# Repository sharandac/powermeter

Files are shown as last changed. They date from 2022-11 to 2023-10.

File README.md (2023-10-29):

<p align="center">

&nbsp;

&nbsp;

</p>
<hr/>

# powermeter

A not so simple but very flexible smart meter based on ESP32. It supports MQTT, live monitoring via web interface, IO ports ( can be switched depending on measured values ), a simple OLED driver for simple value reports, editable opcode sequences per channel and group management. And the best is: everything can also be set via the web interface and has immediate effect and invites to play to improve the understanding of AC voltage/current or DC voltage/current.<br>
<h3 style="color:#00ff00">Note: From version 2022110101 a complete reconfiguration is required.</h3>
<h3 style="color:#ff0000">Danger: Working with 110V or 230V is dangerous!</h3>

# install

Clone this repository and open it with platformIO. Remember, the SPIFF must also be flashed. On a terminal in vscode you can do it with
```bash
pio run -t uploadfs
pio run -t upload
```

After that, take a look at your monitorport ...

```text
Read config from SPIFFS
scan for SSID "" ... not found
starting Wifi-AP with SSID "powermeter_aadee0"
AP IP address: 192.168.4.1
Start Main Task on Core: 1
Start NTP Task on Core: 1
Start Measurement Task on Core: 0
Start MQTT-Client on Core: 1
Start Webserver on Core: 1
NTP-client: renew time
Start OTA Task on Core: 1
Failed to obtain time
NTP-client: Thursday, January 01 1970 01:00:07
```
When the output look like this, congratulation!

After the first start an access point will be opened with an unique name like
```bash
powermeter_XXXXX
```
and an not so unique password
```bash
powermeter
```
After that you can configure the powermeter under the following IP-address with your favorite webbrowser
```bash
http://192.168.4.1 or powermeter_xxxxxx.local
```
# how it works

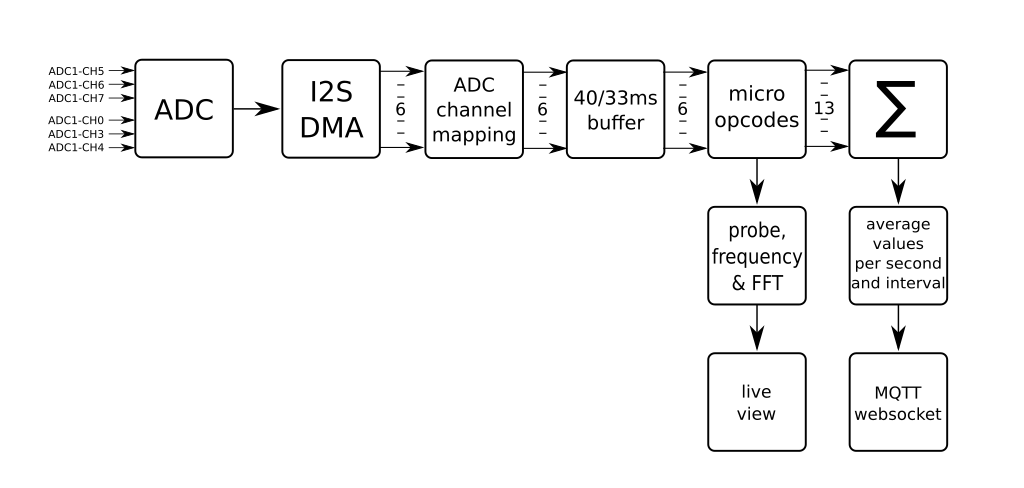
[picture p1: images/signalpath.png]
signalpath


At any time, all 6 adc channel are read in simultaneously regardless of the settings. Afterwards, these 6 ADC channels are distributed to 13 virtual channels with the help of editable microopcodes, each sample has a maximum of 10 opcodes available for real-time calculations (mixing, sum calculation, reactive power and so on). These 13 virtual channels can then be combined into a maximum of 6 output groups. For more information about how AC current or three-phase current and power calculations works, [read here](https://en.wikipedia.org/wiki/Alternating_current) and [here](https://en.wikipedia.org/wiki/Three-phase_electric_power)

# sensor hardware

## Sensors
SCT013-000 current sensor (~100A)<br>
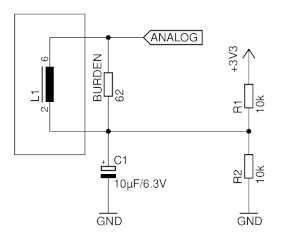
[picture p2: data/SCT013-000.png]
SCT013-000 current sensor (~100A)


ZMPT101B voltage sensor (~250V)<br>
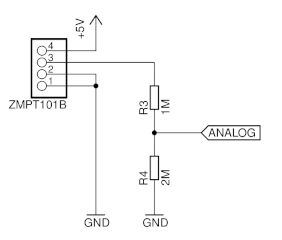
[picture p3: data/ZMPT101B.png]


ACS712 current sensor 5A, 20A and 30A<br>
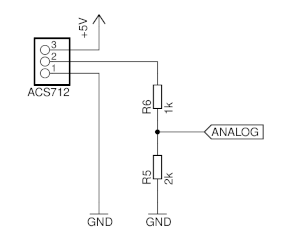
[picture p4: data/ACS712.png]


simple voltage divider<br>
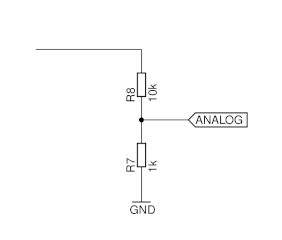
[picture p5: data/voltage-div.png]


For ratio calculation see inline documentation via webinterface.

## Display hardware
Uncomment in "**display.cpp**" the line of the display you want to use<br>
```c
//#include <Adafruit_SSD1306.h>
//#include  <Adafruit_SH110X.h>
```

# Interface

## live view
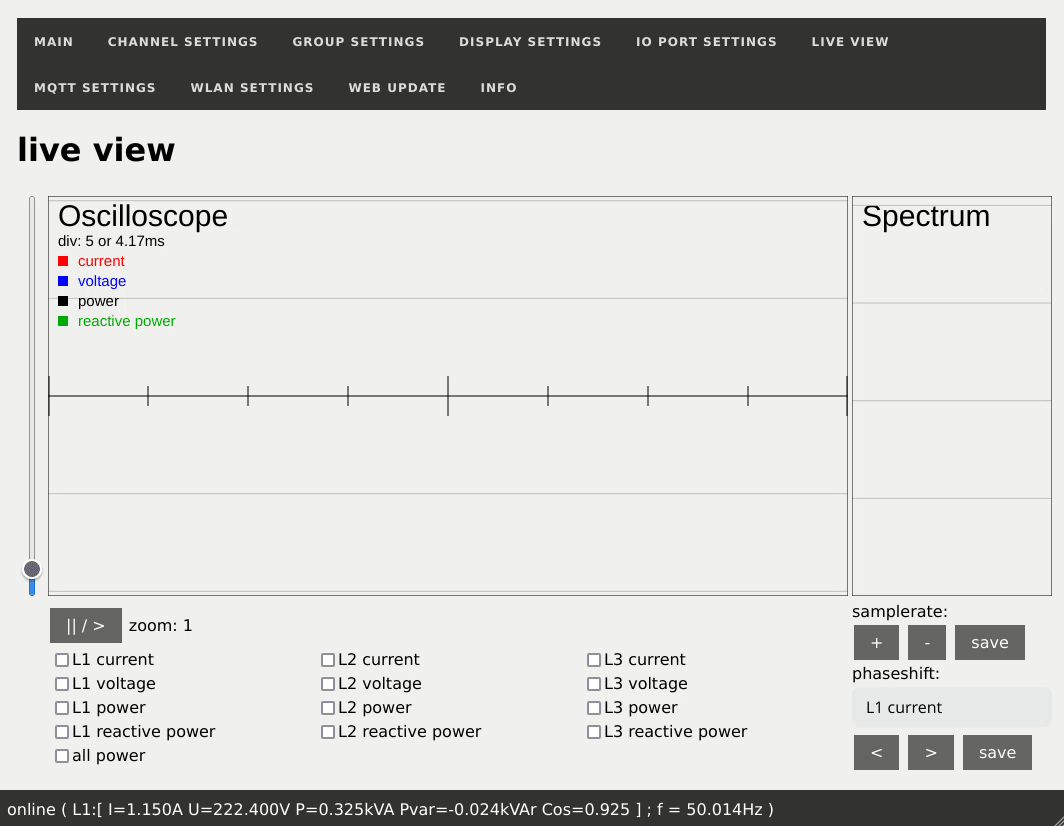
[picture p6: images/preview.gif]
live view

## round trip
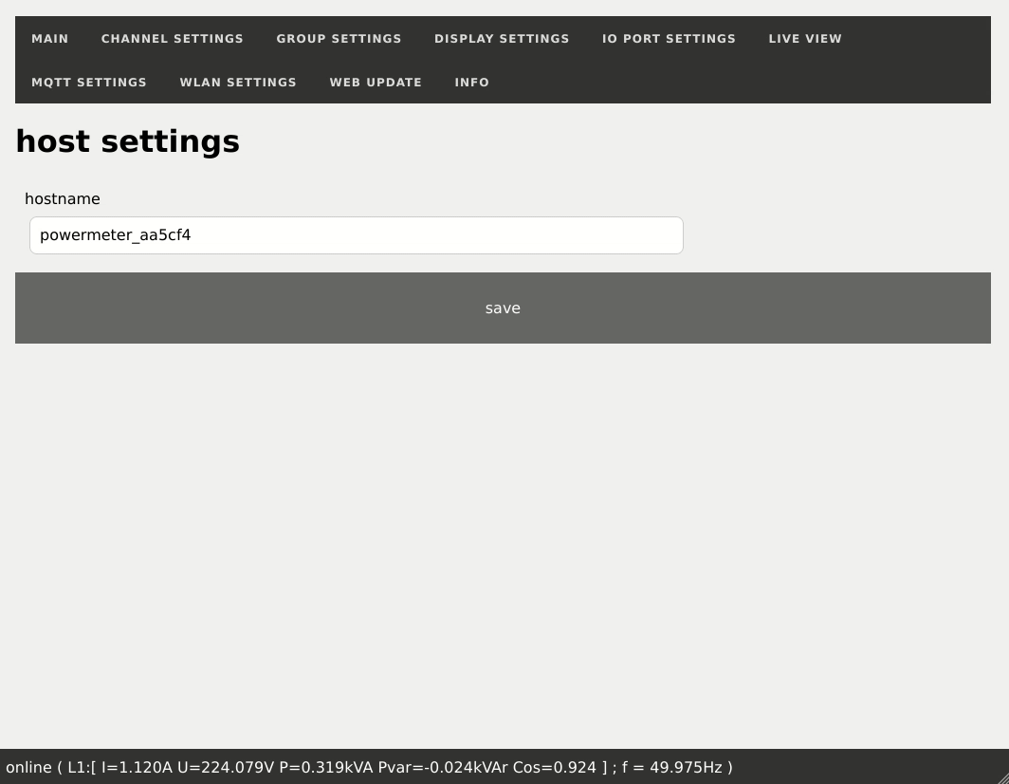
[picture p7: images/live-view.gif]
round trip


# contributors

Every Contribution to this repository is highly welcome! Don't fear to create pull requests which enhance or fix the project, you are going to help everybody.
<p>
If you want to donate to the author then you can buy me a coffee.
<br/><br/>

</p>

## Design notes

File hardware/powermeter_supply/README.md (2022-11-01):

# powermeter with supply

Here is the simplest standalone powermeter with supply you can build with current and voltage measurement.

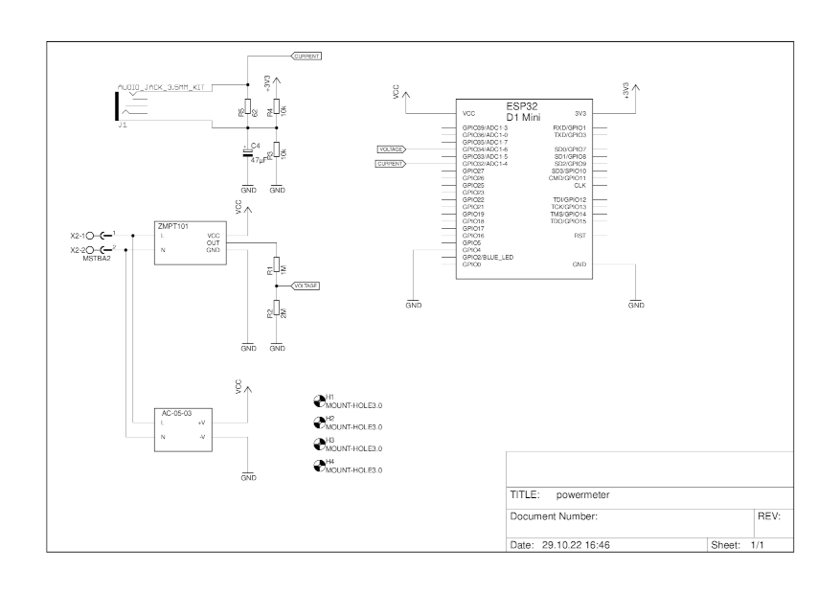
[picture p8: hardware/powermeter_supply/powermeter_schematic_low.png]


## eagle files

[schematic](powermeter.sch)<br>
[board](powermeter.brd)

## bill of material

1 x 150x100x1mm 35µm FR4 [amazon](https://amzn.eu/d/hufknsN)<br>
esp32 D1 mini [amazon](https://amzn.eu/d/gZaocqF)<br>
ZMPT101 [amazon](https://amzn.eu/d/3shv3Ax)<br>
SCT-013-000 [amazon](https://amzn.eu/d/5wpwDs4)<br>
AC-05-03 ( 110-250V/AC -> 5V/DC ) [amazon](https://amzn.eu/d/ckoURve)<br>
3.5mm jack [amazon](https://amzn.eu/d/a7YUG0G)<br>
MSTBA2 connector [amazon](https://amzn.eu/d/0bCERTn)<br>
2 x 10k resistor<br>
1 x 62R resistor<br>
1 x 1M resistor<br>
1 x 2M resistor<br>
1 x 47µF cap<br>

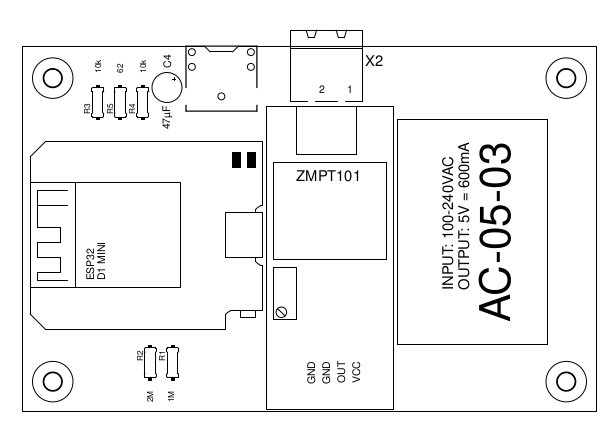
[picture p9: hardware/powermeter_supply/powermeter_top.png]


## gcode

The G-code files are intended for Chilipeppr with a CNC3018 and contain everything. Engraving, drilling and cutting. There are two files. A normal one, where you should have your own gcode for tool change and length measurement and one with the appropriate gcode that also contains the length measurement. The reference point is X=0 and Y=0.

A backlash-free Z-axis is very important for accurate engraving of the tracks and cutting out!

The following tools are required:

0.1mm milling bit<br>
0.6mm drill bit<br>
0.9mm drill bit<br>
1.2mm drill bit<br>
1.3mm drill bit<br>
1.4mm drill bit<br>
2.0mm end mill<br>

Drag and drop the preferred gcode file into Chilipeppr. Autoleveling is a must. And then just press play. For the tool change, the program is paused at the appropriate position (M6).

If everything has gone well, you are rewarded with a finished board without any post-processing and is ready to soldering.

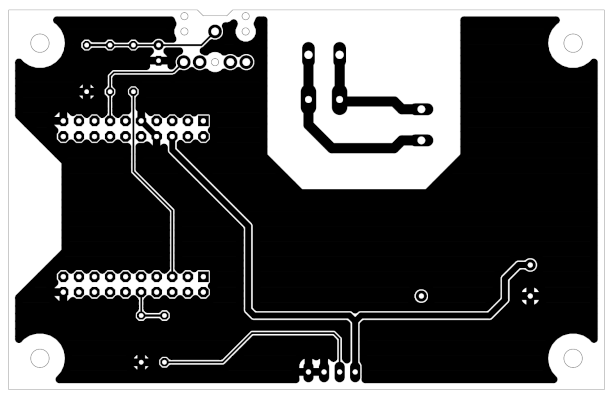
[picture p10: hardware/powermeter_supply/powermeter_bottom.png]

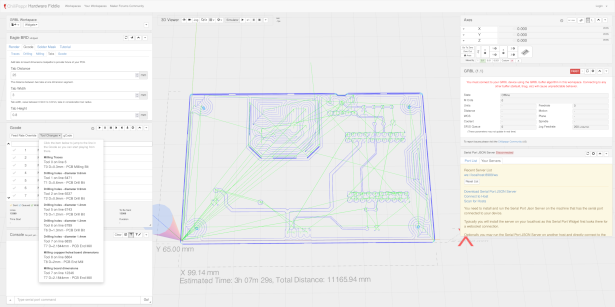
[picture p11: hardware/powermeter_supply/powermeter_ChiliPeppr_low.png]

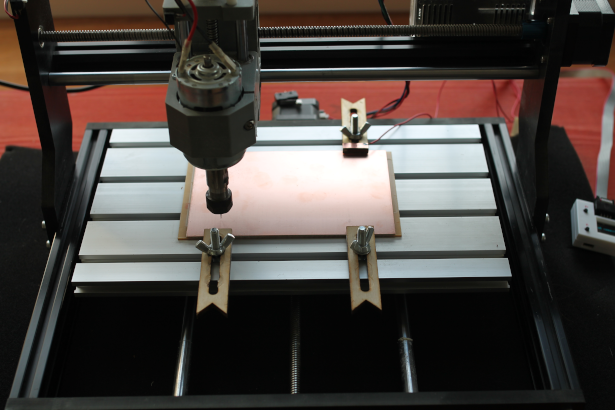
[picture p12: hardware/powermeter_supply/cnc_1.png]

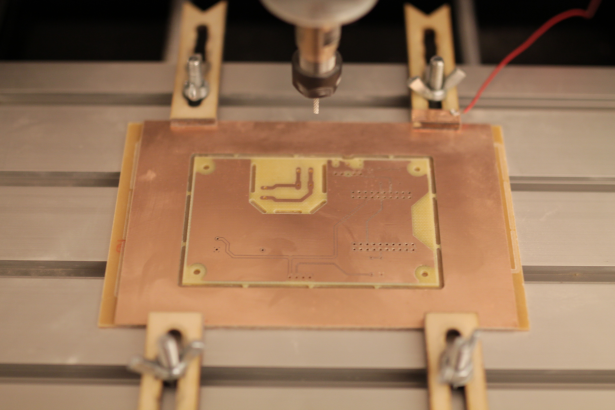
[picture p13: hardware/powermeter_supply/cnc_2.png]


## config

After soldering and software installtion (wifi,mqtt and so on) you can copy the content from config/measure.json to your powermeter. From here you can tweake the ratio settings for precise measuring via web interface under "channel settings".

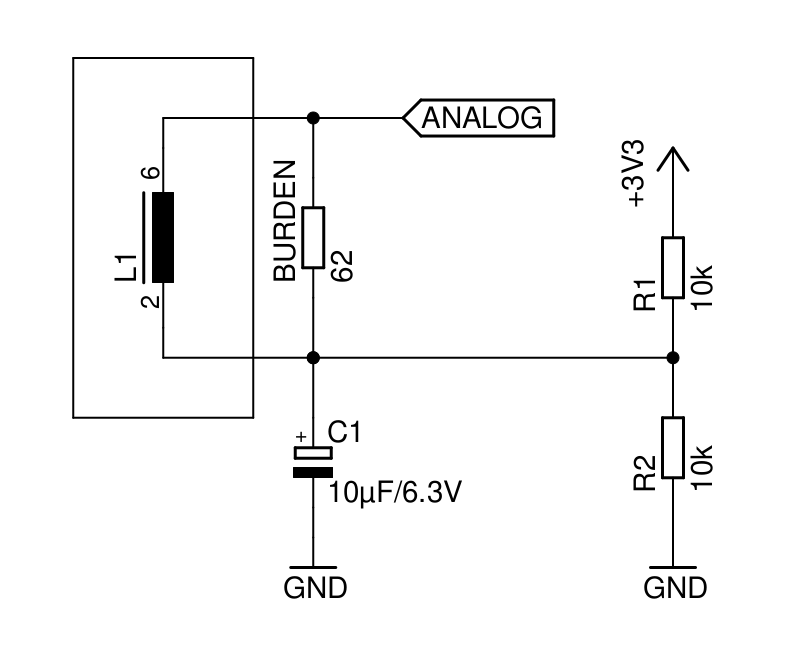
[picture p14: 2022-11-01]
images/schematic.png

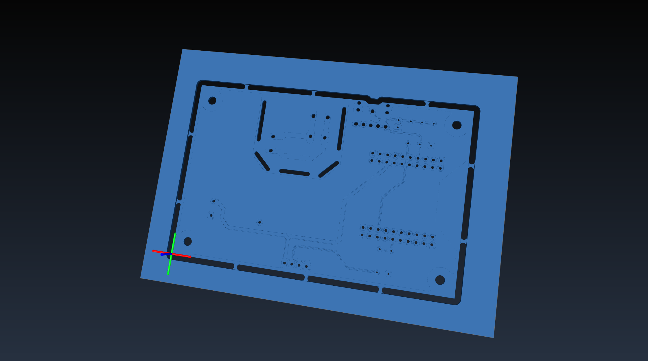
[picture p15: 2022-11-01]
hardware/powermeter_supply/gocde/powermeter.png

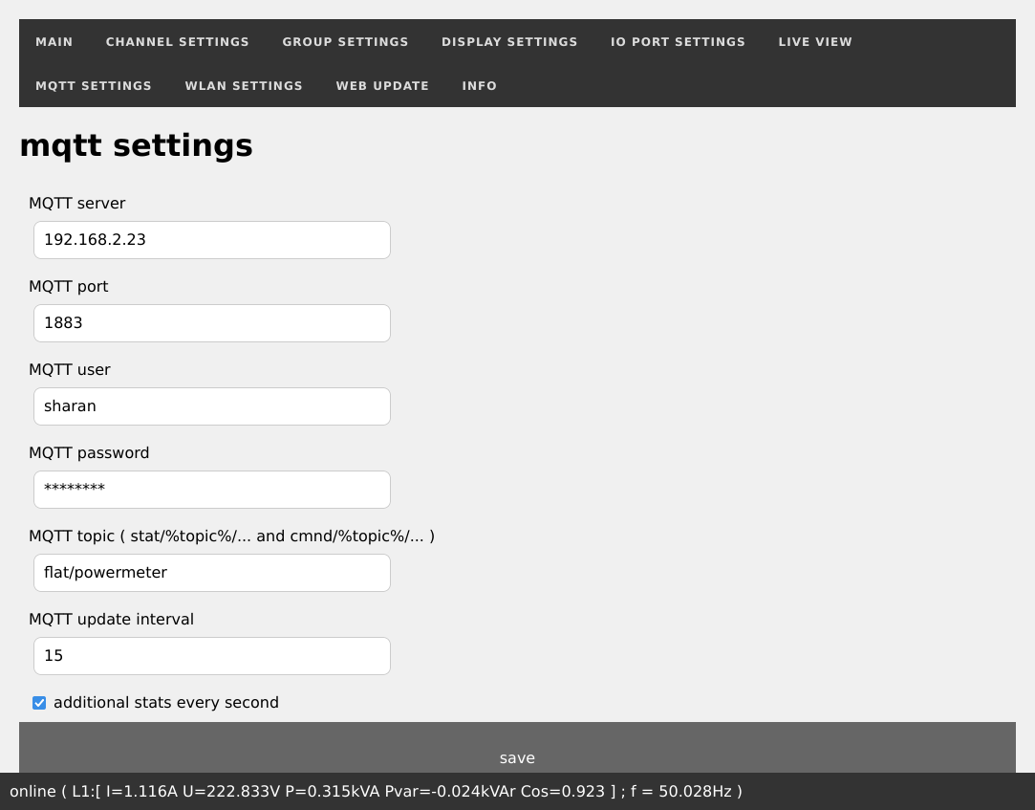
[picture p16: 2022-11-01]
images/mqtt-setting.png

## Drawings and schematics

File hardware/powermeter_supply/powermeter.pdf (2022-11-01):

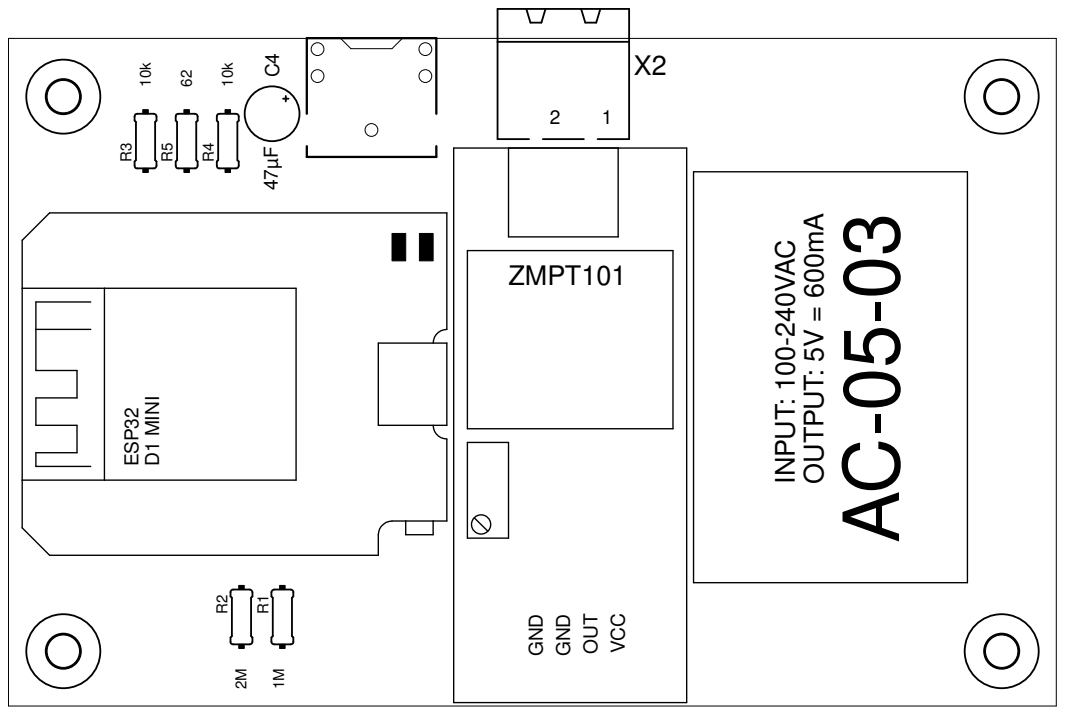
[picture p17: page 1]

ESP32 D1 MINI VCC OUT GND GND ZMPT101 2 1 AC-05-03 INPUT: 100-240VAC OUTPUT: 5V = 600mA R1 R2 R3 R4 R5 C4X2 1M2M 10k 10k 62 47µF

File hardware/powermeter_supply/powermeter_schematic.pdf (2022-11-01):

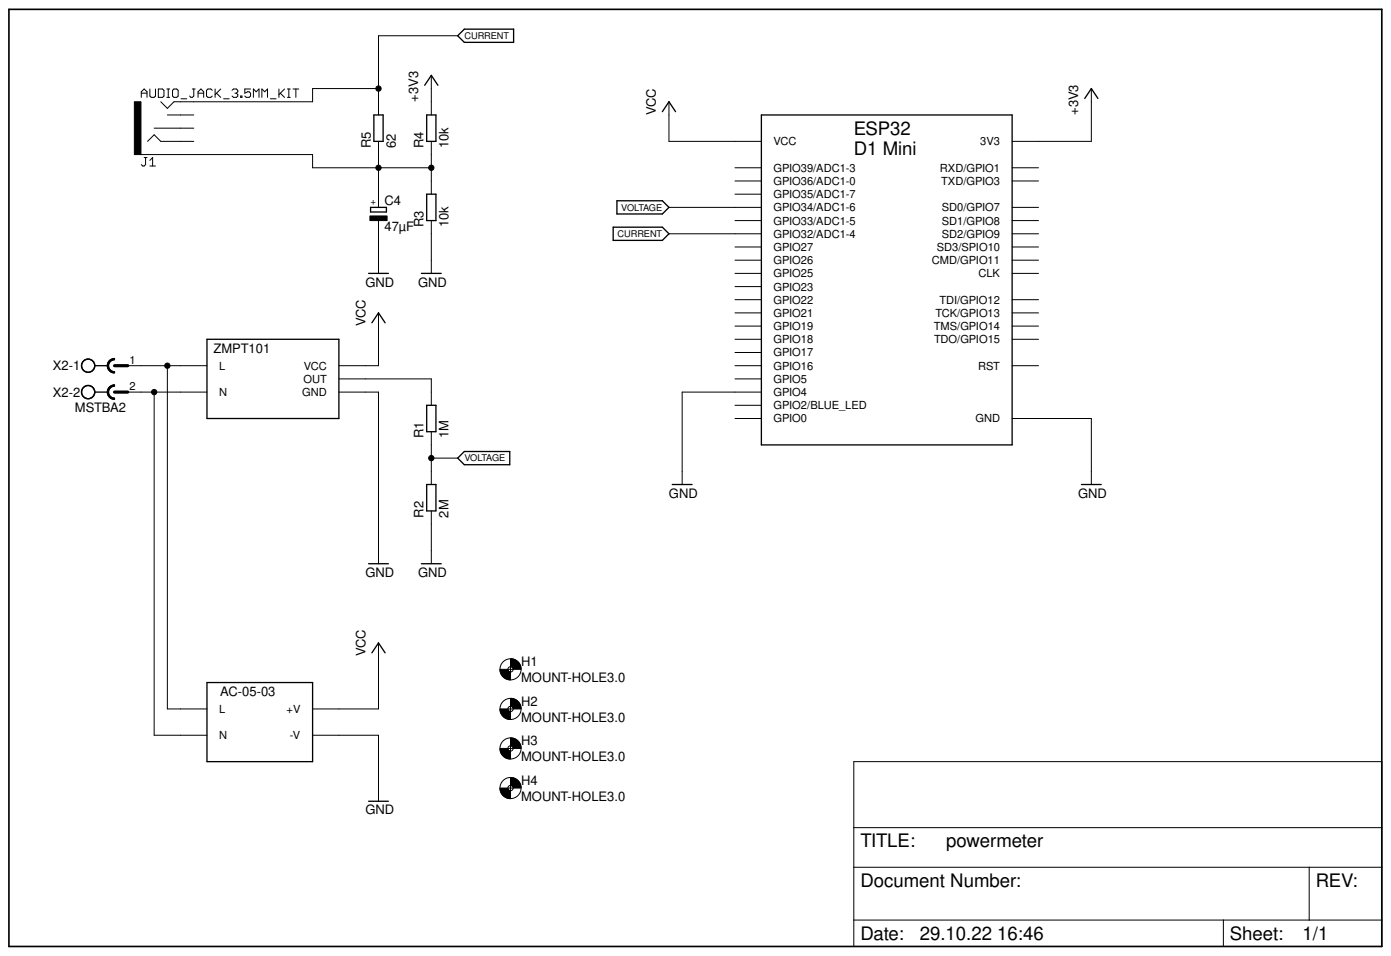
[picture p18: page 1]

Document Number: | REV:

Date: 29.10.22 16:46 | Sheet: 1/1

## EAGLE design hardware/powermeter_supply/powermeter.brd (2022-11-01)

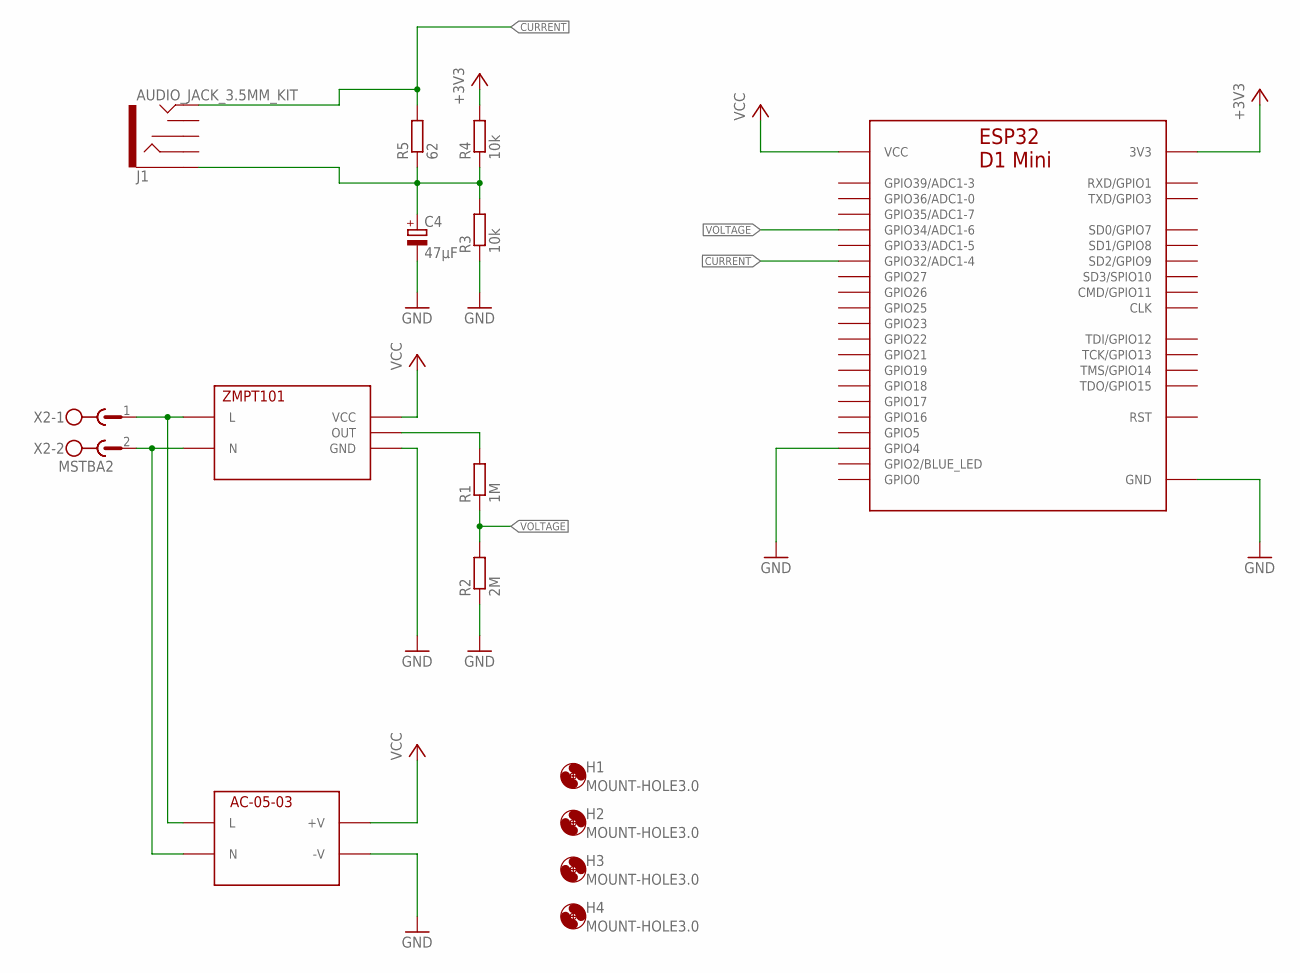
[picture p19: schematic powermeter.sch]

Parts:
C4: 47µF; E2,5-5
H1, H2, H3, H4: MOUNT-HOLE3.0; 3,0
J1: AUDIO_JACK_3.5MM_KIT; AUDIO-JACK-KIT
R1: 1M; 0204/7
R2: 2M; 0204/7
R3, R4: 10k; 0204/7
R5: 62; 0204/7
U1: ESP32D1MINI
U$1: ZMPT101
U$2: AC-05-03
X2: MSTBA2

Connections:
+3V3: R4.2, U1.3V3
CURRENT: J1.TIP, R5.2, U1.IO32 (GPIO32/ADC1-4)
GND: C4.-, R2.1, R3.1, U1.GND1 (GND), U1.GND2 (GND), U1.GND3 (GND), U1.IO4 (GPIO4), U$1.P$3 (GND), U$1.P$4 (GND), U$2.-V
unnamed: R1.2, U$1.OUT
unnamed: U$1.L, U$2.L, X2.1
unnamed: C4.+, J1.SLEEVE, R3.2, R4.1, R5.1
unnamed: U$1.N, U$2.N, X2.2
VCC: U1.VCC, U$1.VCC, U$2.+V
VOLTAGE: R1.1, R2.2, U1.IO34 (GPIO34/ADC1-6)

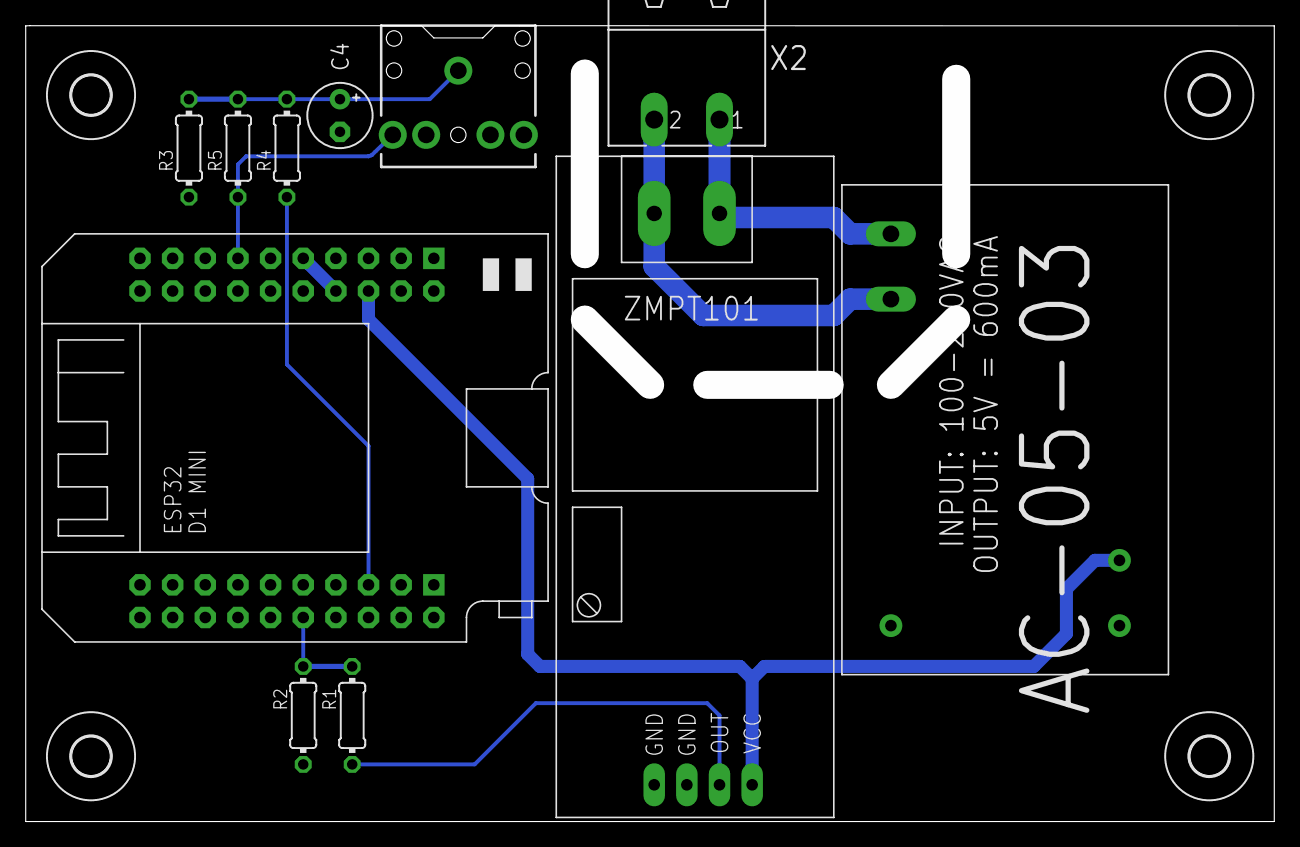
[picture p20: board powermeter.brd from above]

Board: 2 copper layers, 97.1 x 61.9 mm, 15 parts (0 on the bottom side), 9 nets.

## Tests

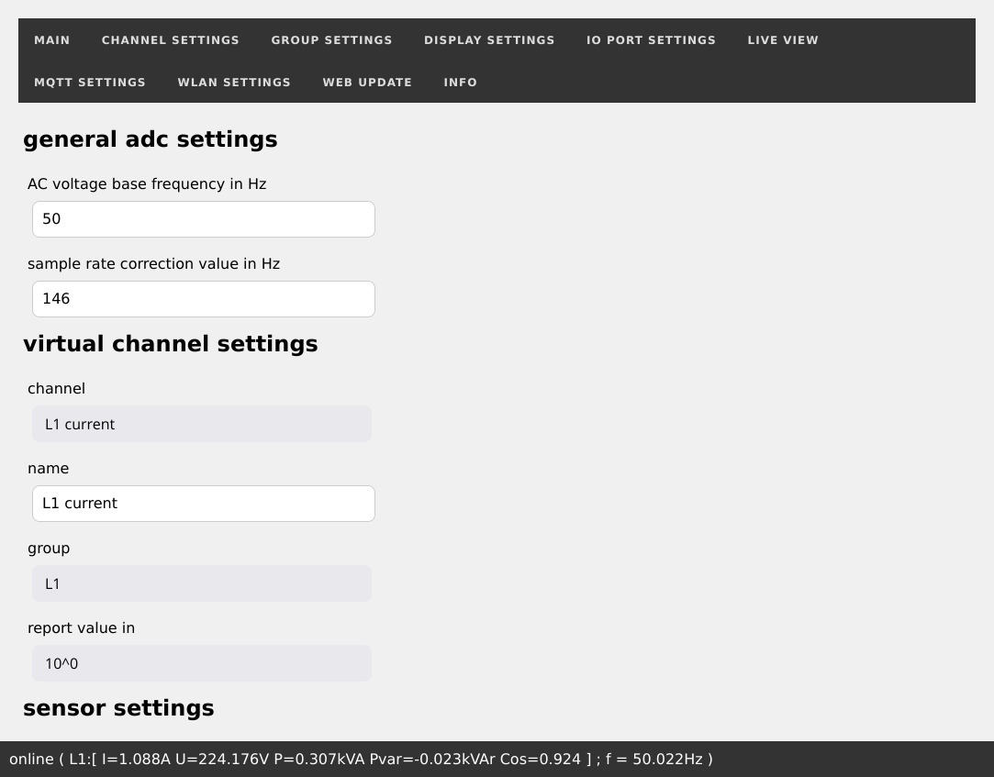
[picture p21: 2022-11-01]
images/measurement-setting.png

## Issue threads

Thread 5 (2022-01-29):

Unable connect to wifi network

STableThink, 2022-01-29:
When trying to connect to my own personal wifi ap (and other test access points), the debug console only shows this error at startup:
```
scan for SSID "stsopenwrt" ... found
connect to stsopenwrt (****)
WiFi lost, restart ... failed
starting Wifi-AP with SSID "powermeter1"
```
So the esp is unable to log into my home network.
Best regards
Jonas

sharandac, 2022-03-22:
Thanks for your feedback. I have also seen this error from time to time. The ESP32 will probably connect correctly to your network later when your settings are right. With Firefox, you can then connect to "http://powermeter1.local" without knowing the IP.

"powermeter1" is your Wifi AP SSID in this case.

Otherwise, let me know ...

Closed 2022-04-28.

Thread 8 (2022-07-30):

Question: Precision for 3phase setup?

gytisgreitai, 2022-07-30:
Hi, thanks for the nice write up and detailed diagram! I have a bit offtopic question, how precise do you find the readings of these clamps without voltage measuring? I’m contemplating about using this diy vs buying ready made product like shelly. Do you calibrate them somehow?

sharandac, 2022-08-01:
Thank you for your feedback. The square-root measurement method is quite accurate, even if the ADC is not. Just like the SCT-013-0x0 converters. But that's not a problem if you have a consumer from which you know the exact power consumption. With this, you can calibrate everything precisely.
I have an exact 2kW consumer that has been precisely measured for me.
I get +/-0.5 % accuracy with 2kW. Of course, as with all measuring methods, it becomes less accurate in the lower range.
The voltage can also be measured using the same method (small 9 V transformer or [link](https://www.amazon.de/gp/product/B08ZDQ77ZC/ref=ppx_yo_dt_b_asin_title_o04_s00?ie=UTF8&psc=1)) and then calculated. Or you can simply enter 230 or 110 volts.
I also recommend using the experimental branch, which works better but is not yet completely finished because I lack some time.

Closed 2022-08-11.

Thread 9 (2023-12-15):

Saving settings

Vovick1971, 2023-12-15:
Hello.
Thank you for the work you've done. I have been looking for a similar project for a very long time. It is completely suitable for my tasks.
In my device, I use ESP 32 and ZMPT101B modules to measure mains voltage.
I have one unclear point.
 On the "channel settings" page, I select the voltage measurement channel (for example, L1 voltage), the sensor type (ZMPT101B), set the
 coefficients, save the settings (SAVE button at the bottom of the page), everything works correctly, but if you restart the EPS32 web
 interface page, or restart the module itself, then all settings return to default values (SCT013-000). In this case, incorrect values are
 output. You have to set the parameters again.
 Setting the checkbox to allow real time editing, but don't forget to save your settings also has no effect.
 I can't figure out how to make the set values persist.

Thank you.

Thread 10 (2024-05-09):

error: 'arduinoFFT' was not declared in this scope`

samezrp, 2024-05-09:
If any of you would have compile error:
`src/measure.cpp:480:9: error: 'arduinoFFT' was not declared in this scope`
please be aware lib kosme/arduinoFFT@=1.5.6 is not backword compatible.

Easiest solution is to update _platformio.ini_ file and change:
`kosme/arduinoFFT@>=1.5.6`
to
`kosme/arduinoFFT@=1.5.6`

**>=** replace with **=**

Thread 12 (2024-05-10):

L2 filter problem

samezrp, 2024-05-10:
I would like to rise another problem.
I'm preparing my implementation of your PowerMeter and I can see there is a problem with channel connected to: ADC1-CH7 (GPIO35).
I have HW with all 3 current lines connected to SCT013-030 installed on the same wire + 3 ZMPT101B fed with the same voltage. So all 3 voltage and 3 current reading should be the same.
And when you look at live view all is the same, but when you take a closer look at L2 and current, it is seen that this value is different and is not stable as others.
Take a look at this video:
[https://youtu.be/L46QpZTydEg](url)
on oscilloscope readings for L1 and L2 are the same. But when you look at spectrum and filtered value you can see difference. On spectrum you can see some pumping, L2 value jumps.
All channels are set the same, my measure.json file below.
@sharandac would you mind helping me with that?
[measure.json](https://github.com/sharandac/powermeter/files/15274634/measure.json)
I checked different ESP32 boards, I played with sensors, channels and look like problem is attached to: ADC1-CH7 (GPIO35) directly.

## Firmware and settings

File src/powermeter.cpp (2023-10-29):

/**
 * @file powermeter.cpp
 * @author Dirk Broßwick (dirk.brosswick@googlemail.com)
 * @brief 
 * @version 1.0
 * @date 2022-10-03
 * 
 * @copyright Copyright (c) 2022
 * 
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
 *  You should have received a copy of the GNU General Public License
 *  along with this program; if not, write to the Free Software
 *  Foundation, Inc., 59 Temple Place - Suite 330, Boston, MA 02111-1307, USA.
 */ 
#include <Arduino.h>
#include <FS.h>
#include <SPIFFS.h>

#include "config.h"
#include "display.h"
#include "ioport.h"
#include "measure.h"
#include "mqttclient.h"
#include "ntp.h"
#include "webserver.h"
#include "wificlient.h"
/**
 * @brief arduino setup function
 */
void setup( void ) {
    setCpuFrequencyMhz( 240 );
    Serial.begin(115200);
    /*
     * hardware stuff and file system
     */
    log_i("Start Main Task on Core: %d", xPortGetCoreID() );
    if ( !SPIFFS.begin() ) {
        log_i("format SPIFFS ..." );
        SPIFFS.format();
    }
    ioport_init();
    display_init();
    wificlient_init();
    /*
     * Setup Tasks
     */
    measure_StartTask();
    mqtt_client_StartTask();
    asyncwebserver_StartTask();
    ntp_StartTask();
}

/**
 * @brief arduino main loop
 */
void loop() {
    display_loop();
    ioport_loop();
}

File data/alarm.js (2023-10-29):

var pause_osc = true;
var connect = false;
var timeout = 3;
var savecounter = 0;
var connection;

getconnect();
setInterval(function () {getStatus();}, 1000);

function getconnect() {
    connection = new WebSocket('ws://' + location.hostname + '/ws', ['arduino']);

    connection.onopen = function () {
        connect = true; 	
        sendCMD("STA");

        if( document.getElementById( 'OScope' ) )
            sendCMD( "get_channel_list" );

        if( document.getElementById( 'measurement_settings' ) ) {
            sendCMD( "get_measurement_settings" );
            sendCMD( "get_channel_config" );
        }

        if( document.getElementById( 'wlan_settings' ) )
            sendCMD( "get_wlan_settings" );

        if( document.getElementById( 'group_settings' ) )
            sendCMD( "get_group_settings" );

        if( document.getElementById( 'mqtt_settings' ) )
            sendCMD( "get_mqtt_settings" );

        if( document.getElementById( 'hostname_settings' ) )
            sendCMD( "get_hostname_settings" );

        if( document.getElementById( 'display_settings' ) )
            sendCMD( "get_display_settings" );

        if( document.getElementById( 'ioport_settings' ) )
            sendCMD( "get_ioport_settings" );
    };

    connection.onmessage = function (e) {
        console.log('Server: ', e.data);
        partsarry = e.data.split('\\');
    
        if( partsarry[0] == 'OScopeProbe' ) {
            GotOScope(e.data );
            return;
        }
        
        if( partsarry[0] == 'status' ) {
            if ( partsarry[1] == 'Save' ) {
                document.getElementById('fixedfooter').style.background = "#008000";
                savecounter = 2;
            }
            else {
                document.getElementById('status').firstChild.nodeValue = partsarry[1];
            }
    
            timeout = 4;
            return;
        }
  
        if(partsarry[0] == 'get_channel_list' ) {
            if ( document.getElementById( partsarry[1] ) ) {
                const label = document.getElementById( partsarry[1] );
                label.textContent = partsarry[2];
            }
            return;
        }
  
        if(partsarry[0] == 'get_channel_use_list') {
            if ( document.getElementById( partsarry[1] ) ) {
                if ( partsarry[2] == 'true' )
                    document.getElementById( partsarry[1] ).checked = true;
                else
                    document.getElementById( partsarry[1] ).checked = false;
            }
            if ( document.getElementById( partsarry[3] ) ) {
                document.getElementById( partsarry[3] ).options[ partsarry[4] ].text = partsarry[5];
            }
            return;
        }
  	
        if(partsarry[0] == 'get_group_use_list') {
            if ( document.getElementById( partsarry[1] ) && partsarry[2] == 'true' ) {
                document.getElementById( partsarry[1] ).checked = true;
            }
            if ( document.getElementById( partsarry[3] ) ) {
                const label = document.getElementById( partsarry[3] );
                label.textContent = partsarry[4];
            }    
            return;
        }
  
        if( partsarry[0] == 'option') {
            if ( document.getElementById( partsarry[1] ).options[ partsarry[2] ] ) {
                document.getElementById( partsarry[1] ).options[ partsarry[2] ].text = partsarry[3];
                refreshOpcode('channel_opcodeseq_str');
            }
            return;
        }
  	
        if( partsarry[0] == 'label') {
            if ( document.getElementById( partsarry[1] ) ) {
                document.getElementById( partsarry[1] ).textContent = partsarry[2];
            }
            return;
        }
    
        if( partsarry[0] == 'checkbox') {
            if ( document.getElementById( partsarry[1] ) ) {
                if( partsarry[2] == 'true' )
                    document.getElementById( partsarry[1] ).checked = true;
                else
                    document.getElementById( partsarry[1] ).checked = false;
            }
            return;
        }

        if ( document.getElementById( partsarry[0] ) ) {
            document.getElementById( partsarry[0] ).value = partsarry[1];
            if( document.getElementById( 'channel_opcodeseq_str' ) )
                refreshOpcode('channel_opcodeseq_str');
        }
    }

    connection.onclose = function(e) {
        console.log('Socket is closed. Reconnect will be attempted in 1 second.', e.reason);
        connect = false;
        setTimeout(function() { getconnect(); }, 1000);
    };

    connection.onerror = function (error) {
        connect = false; 
        console.log('WebSocket Error ', error);
        connection.close();
    };
}

function setSensor( sensor ) {
    console.log('Server: ', sensor );
	partsarry = sensor.split('\\');
	
	console.log('Sensor ratio: ', partsarry[ 0 ] );
	console.log('Sensor phaseshift: ', partsarry[ 1 ] );
	console.log('Sensor offset: ', partsarry[ 2 ] );
	
	if( document.getElementById( 'channel_ratio' ) )
	    document.getElementById( 'channel_ratio' ).value = partsarry[ 0 ];
	if( document.getElementById( 'channel_phaseshift' ) )
	    document.getElementById( 'channel_phaseshift' ).value = partsarry[ 1 ];
	if( document.getElementById( 'channel_offset' ) )
	    document.getElementById( 'channel_offset' ).value = partsarry[ 2 ];
	if( document.getElementById( 'channel_true_rms' ) ) {
  	if( partsarry[ 3 ] == 'true' ) 
	    document.getElementById( 'channel_true_rms' ).checked = true;
	  else
	    document.getElementById( 'channel_true_rms' ).checked = false;
	}
}

function sendCMD( value ) {
    console.log( "Client: " + value );
	if ( connect )
        connection.send( value );
    else
        console.log( "no connection" );
}
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

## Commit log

2019-07-13 some performace and stability improvement
    [measure.cpp, webserver.cpp]
2019-11-11 some issue with AsyncTCP, fix to version 1.0.3
    [measure.cpp]
2020-05-27 switch to the internal i2s interface of the built-in adc
2020-06-09 add options for 50/60Hz AC voltage frequency. some css improvements.
2020-06-13 update schematic
2020-06-13 add current information over mqtt for each channel
2020-06-16 fix wlan issue and security fixes
    [powermeter.cpp, webserver.cpp]
2020-06-16 fix data types, send json msg to mqtt
    [measure.cpp, measure.h]
2020-06-18 remove arduino.h
2020-06-25 read for current and voltage measurement
2021-03-02 fix samplefreq correction setup
    [measure.cpp, webserver.cpp]
2021-08-12 add current offset settings
2022-08-01 fix bufferoverflow and esp32 ide version
2022-08-25 some small fixes and docu update
    [measure.cpp, measure.h]
2022-10-01 some fixes and updates
    [alarm.js, measure.cpp, measure.h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]
2022-10-19 fix some bugs and add hardware
    [powermeter.brd, powermeter.sch]
2022-10-31 Update finalisation
    [powermeter.brd, powermeter.sch]

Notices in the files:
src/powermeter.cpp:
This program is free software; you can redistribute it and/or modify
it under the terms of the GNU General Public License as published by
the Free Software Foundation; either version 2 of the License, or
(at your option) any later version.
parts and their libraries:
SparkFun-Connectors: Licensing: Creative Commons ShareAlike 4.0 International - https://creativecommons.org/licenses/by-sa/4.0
